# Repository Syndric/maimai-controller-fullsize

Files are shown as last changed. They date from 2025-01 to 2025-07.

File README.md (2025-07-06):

# Maimai Controller Fullsize

A fullsize homemade maimai machine.
Current guide can be found at [this google doc](https://docs.google.com/document/d/1rlUKWXb57IGA04_7nuOs167HQMNG2UHoSkpQwI1rv1U/edit?usp=sharing).
This guide is not finished yet, but most of the files you need to make the machine are here. READ CAREFULLY!
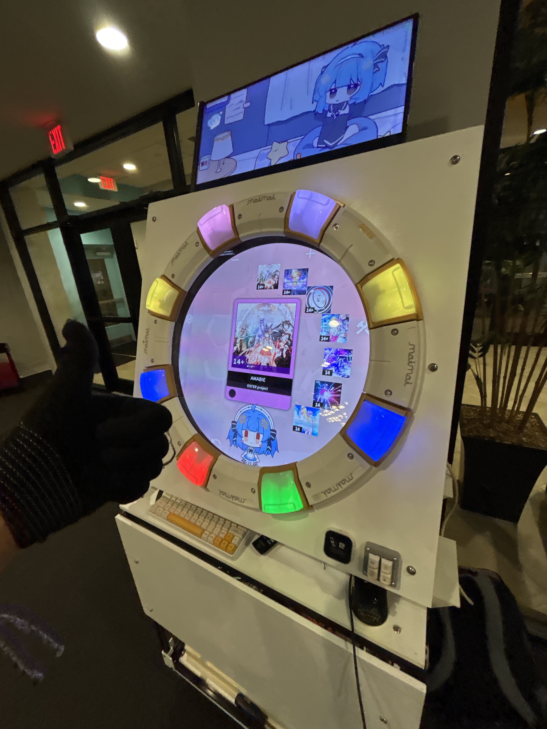
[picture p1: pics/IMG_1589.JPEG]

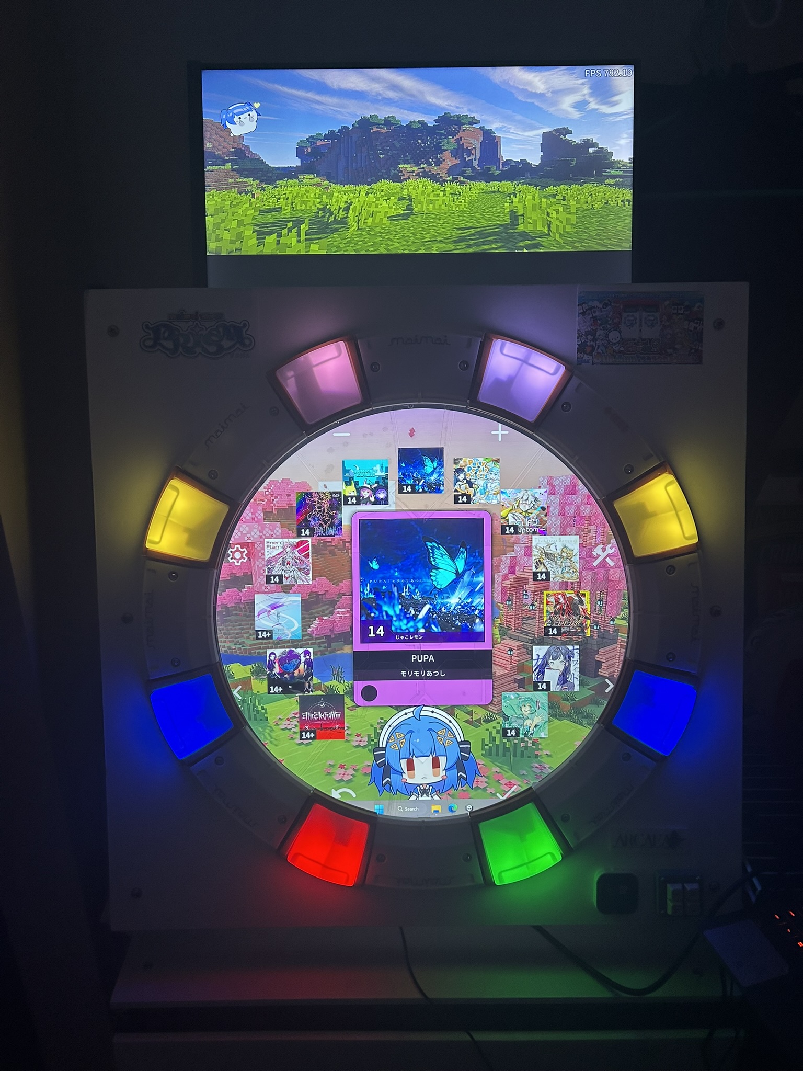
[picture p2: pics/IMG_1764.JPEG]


# Disclaimers

Read [Romper's fullsize guide](https://github.com/ir0nq/maimai-homemade-controller) before reading the instructions here.
DO NOT LASERCUT WITH THE ITO TEMPLATE AS IS. I'm not sure if the traces are wide enough. It's only good to be used for hand tracing/cut.
DO NOT MAKE THE CART IN MY DESIGN. It's not really stable.

I am NOT financially responsible for any mishaps you might have. This is only a guide. Double check all measurements.

# License

CC-NC, feel free to modify the project but don't make any money from this guide.

# Bill of Materials
Not complete

## PCB

- Raspberry Pi Nano
- USB C Connector
- 5.1k ohm resistor 0603
- 1uF capacitor 0603
- MPR121 Modules
- Dupont Pin headers
- JST XH 3 Pin connectors, headers
- 50m red wire
- 20m yellow wire
- 20m black wire
- SN74LV1T34DBVR Level shifter
- WS2812B RGB LED
- Mai pico IO PCB x1
- Syndric's RGB PCB x8

## Main Build

- Rabbit buttons
- ITO Film 40ohm 1m
- 43" TV
- 24" side-to-side Octagon glass
- Chair leg floor protectors
- 2020 48" Aluminum
- Small wood screws for buttons
- Wood screws for mai spacers
- Appropriate spacers

# Tools Needed

- Flathead screwdriver
- Philips screwdriver
- 3D printer
- Router
- Miter saw
- PPE

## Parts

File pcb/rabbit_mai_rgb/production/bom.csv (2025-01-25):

Designator | Footprint | Quantity | Value | LCSC Part #
C1, C2 | 0603 | 2 | C
D1, D2 | LED_WS2812B_PLCC4_5.0x5.0mm_P3.2mm | 2 | WS2812B
J1, J2 | JST_XH_S3B-XH-A_1x03_P2.50mm_Horizontal | 2 | Conn_01x03

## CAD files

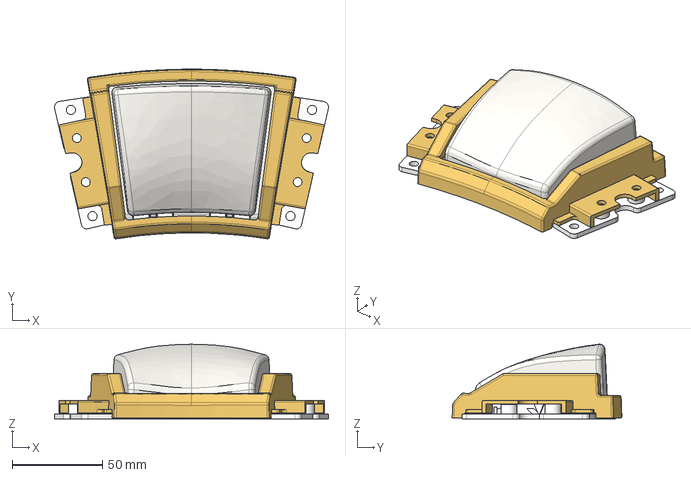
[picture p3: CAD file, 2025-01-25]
cad/Button/ButtonAssembly v7.iges
152.2 x 94.3 x 41.5 mm

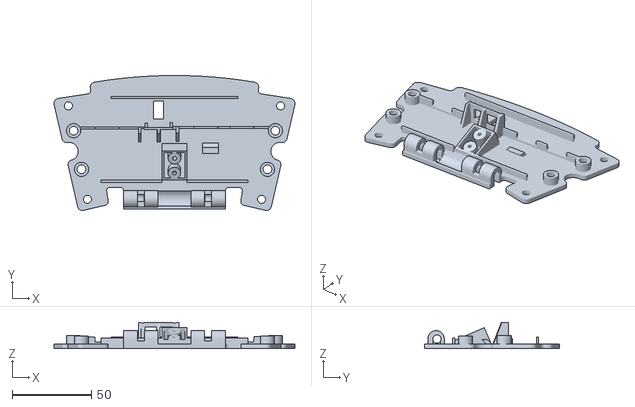
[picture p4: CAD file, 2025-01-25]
cad/Button/ButtonPlate v2.stl
152.2 x 85.3 x 16.4

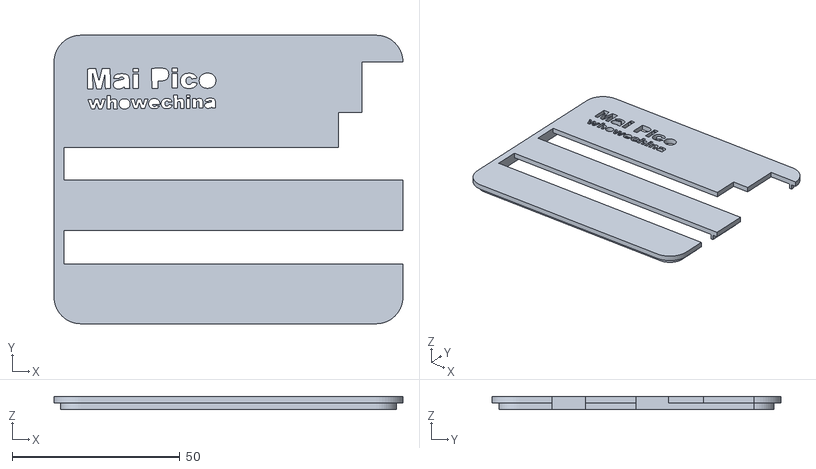
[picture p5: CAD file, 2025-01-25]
cad/IO Board/IOBoard v4_IOBoard v4_Cover_1_Body4.stl
104.0 x 86.0 x 4.00

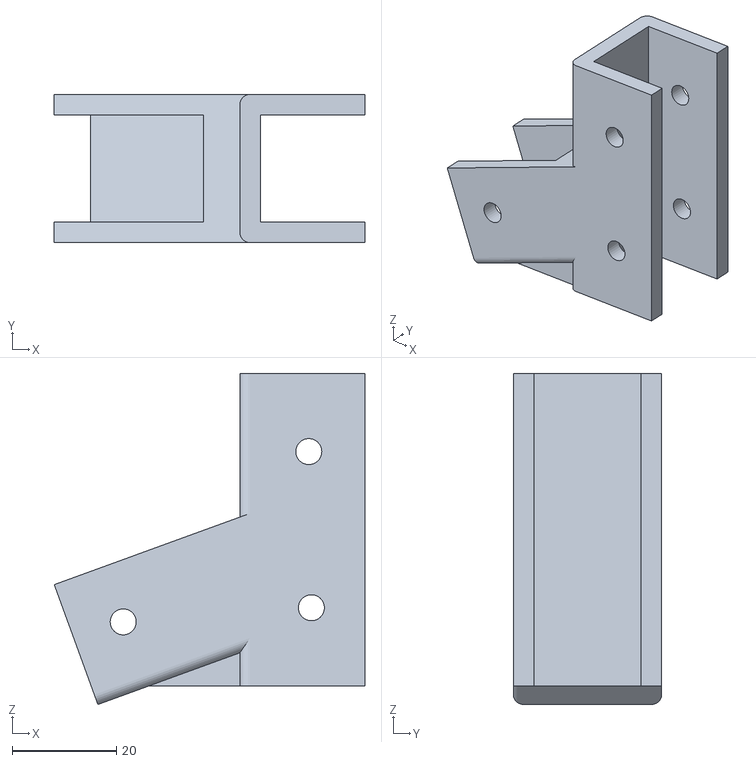
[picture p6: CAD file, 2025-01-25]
cad/Joints/StrongPlate2_70 v2.stl
59.6 x 28.5 x 63.6

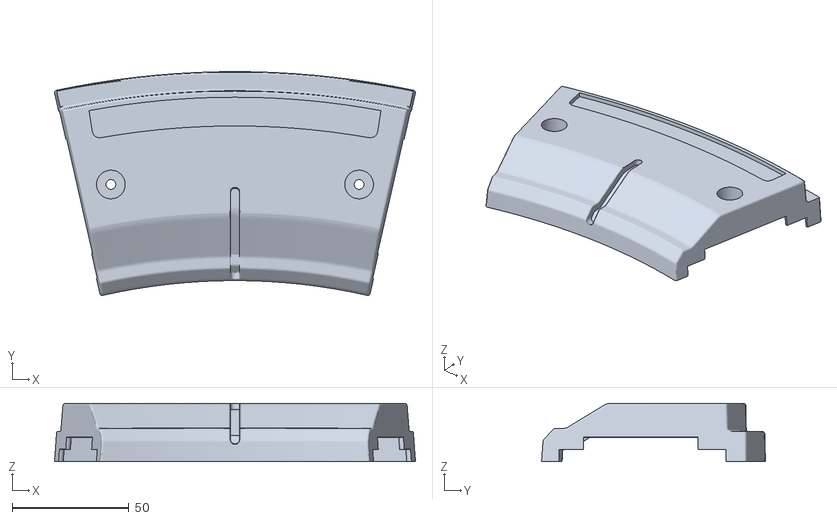
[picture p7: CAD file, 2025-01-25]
cad/Spacer/Maispacer_blank v12.stl
154.5 x 95.8 x 24.9

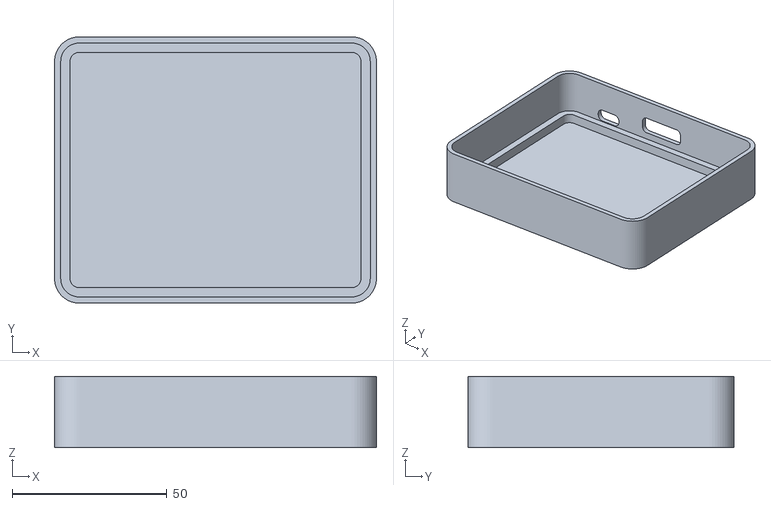
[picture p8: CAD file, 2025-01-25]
cad/IO Board/IOBoard v4_IOBoard v4_Box_1_Body1.stl
104.0 x 86.0 x 23.0

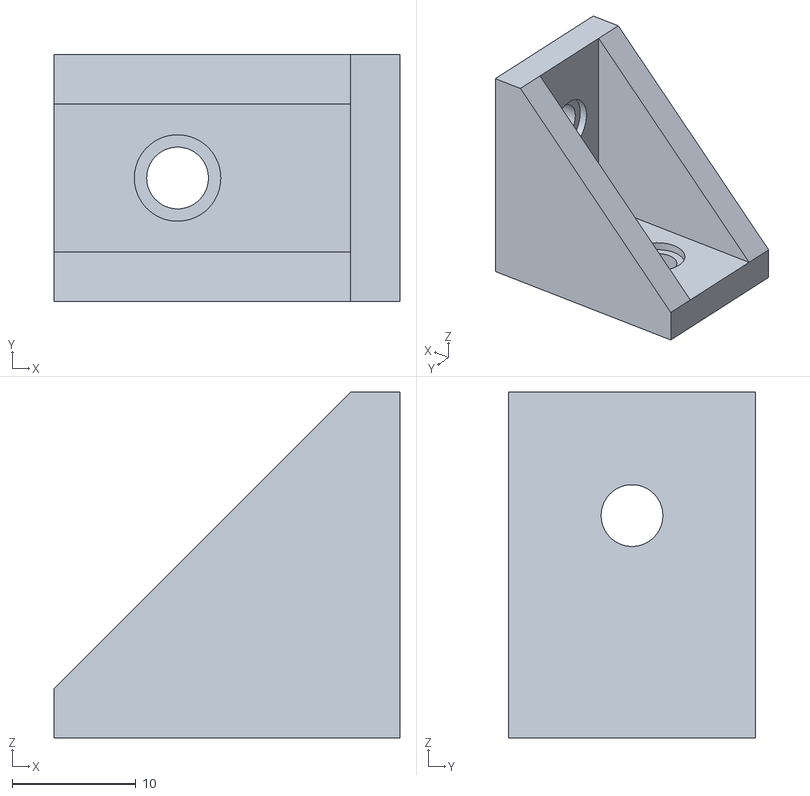
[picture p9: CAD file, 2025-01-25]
cad/Joints/angle bracket 90 v11 .stl
28.0 x 20.0 x 28.0

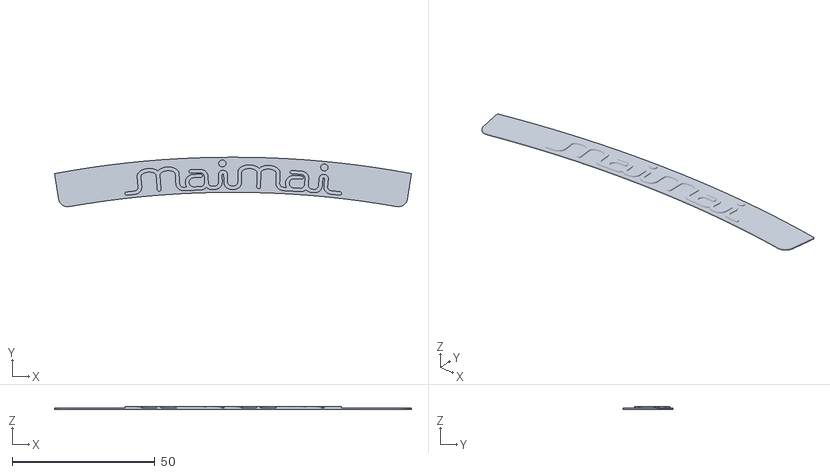
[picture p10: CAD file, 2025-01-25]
cad/Spacer/Maispacer_maidecal v6.stl
124.9 x 17.4 x 1.04

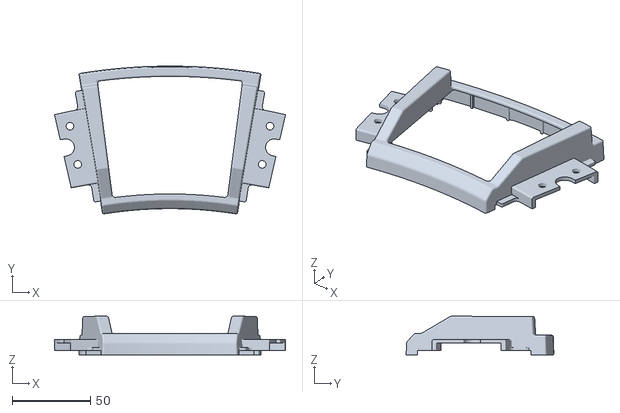
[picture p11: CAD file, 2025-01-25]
cad/Button/ButtonFrame v3.stl
147.4 x 94.3 x 24.6

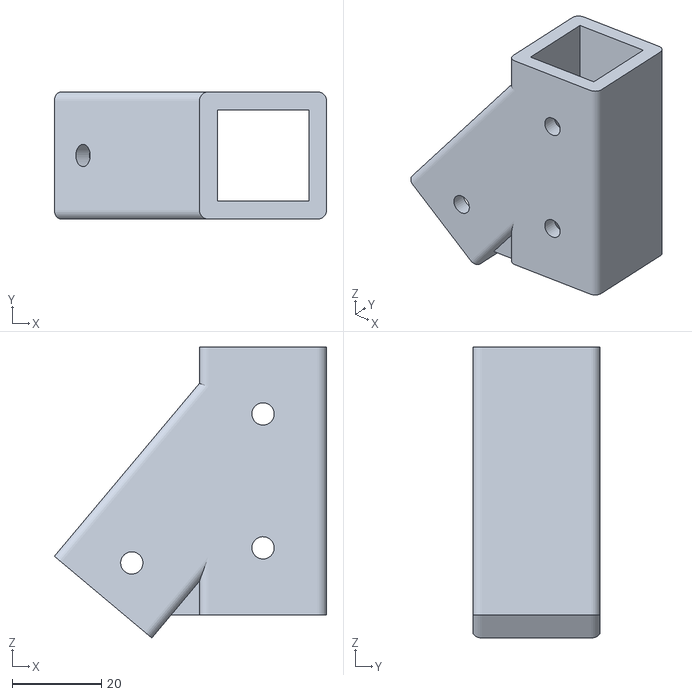
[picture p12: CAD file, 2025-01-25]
cad/Joints/StrongPlate40 v4.stl
61.0 x 28.5 x 65.2

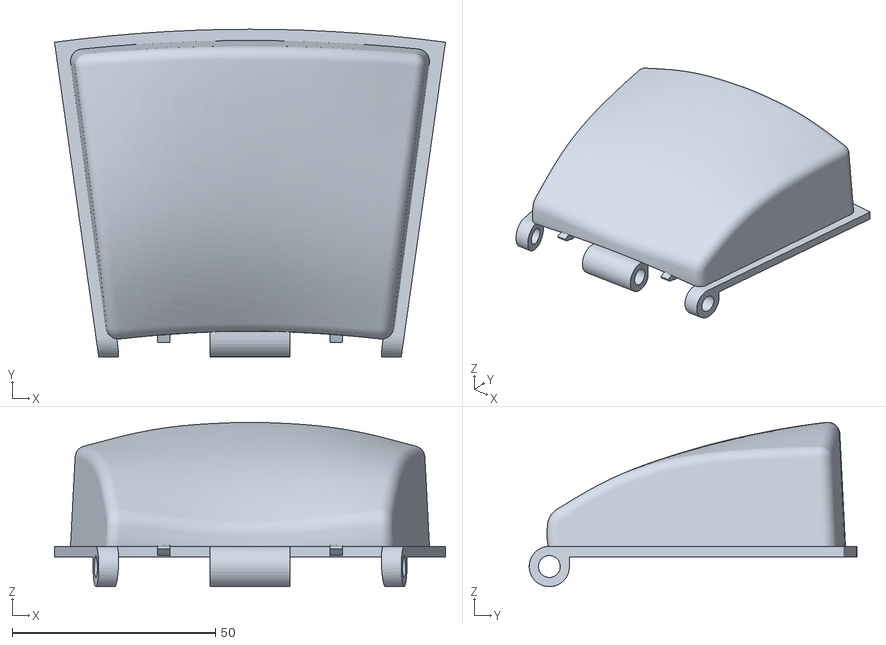
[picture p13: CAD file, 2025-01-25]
cad/Button/MaimaiButton v3.stl
96.3 x 80.6 x 40.5

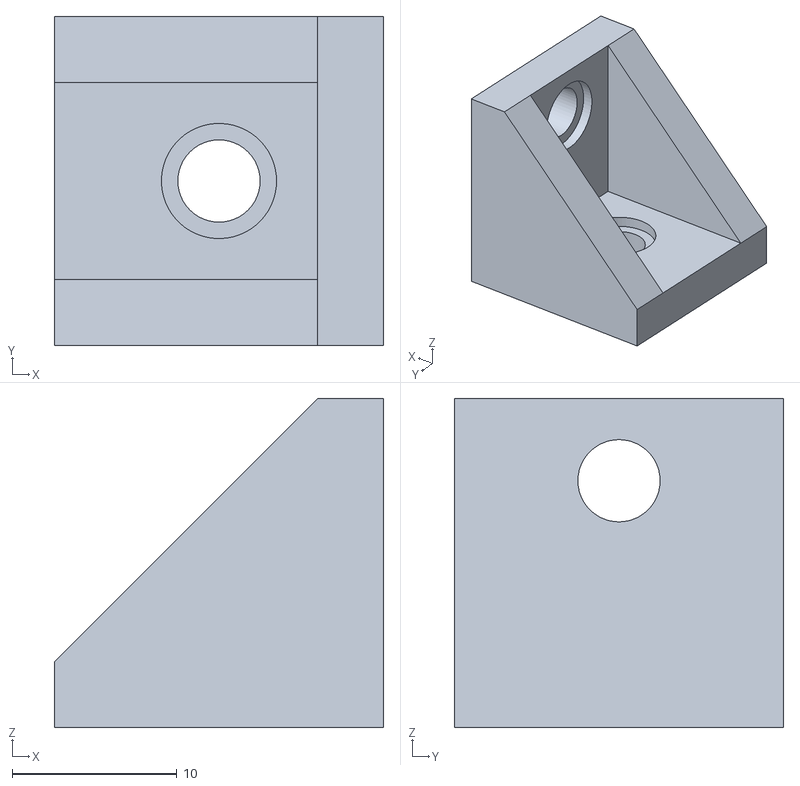
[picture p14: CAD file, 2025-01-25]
cad/Joints/angle bracket 90short v11.stl
20.0 x 20.0 x 20.0

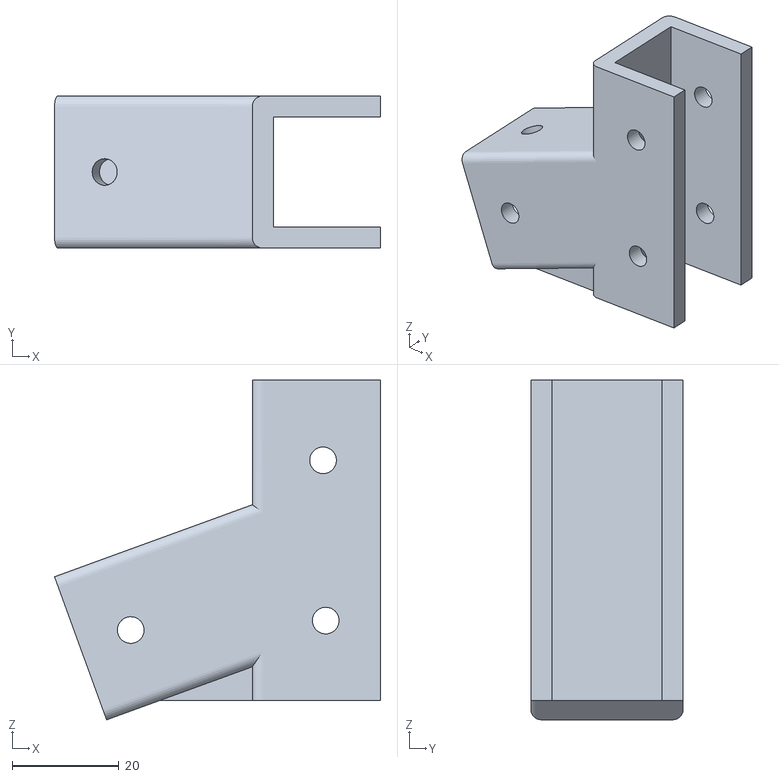
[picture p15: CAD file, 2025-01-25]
cad/Joints/StrongPlate70 v2.stl
61.0 x 28.5 x 63.6

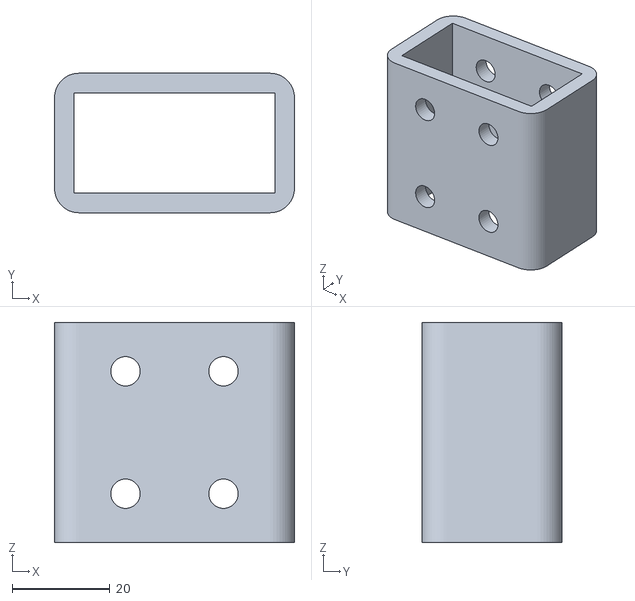
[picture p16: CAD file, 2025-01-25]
cad/Joints/JoiningPlate v6.stl
49.0 x 28.5 x 45.0

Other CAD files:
dxf/mai_pico_ito.dxf
dxf/mai_pico_ito_v1.dwg
dxf/mai_pico_ito_a4.dxf

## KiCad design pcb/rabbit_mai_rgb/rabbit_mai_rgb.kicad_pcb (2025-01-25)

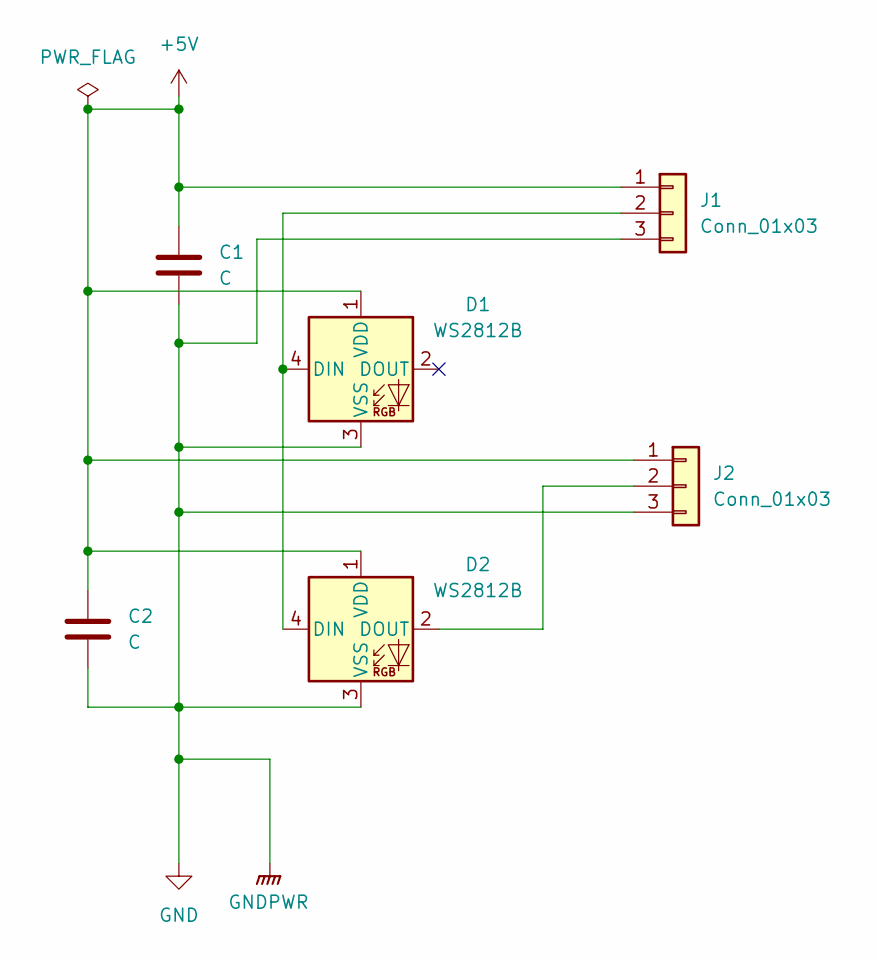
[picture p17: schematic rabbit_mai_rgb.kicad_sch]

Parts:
C1, C2: C; C_0603_1608Metric_Pad1.08x0.95mm_HandSolder
D1, D2: WS2812B; LED_WS2812B_PLCC4_5.0x5.0mm_P3.2mm
J1, J2: Conn_01x03; JST_XH_S3B-XH-A_1x03_P2.50mm_Horizontal

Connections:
+5V: C1.1, C2.1, D1.1 (VDD), D2.1 (VDD), J1.1, J2.1
GND: C1.2, C2.2, D1.3 (VSS), D2.3 (VSS), J1.3, J2.3
unnamed: D1.4 (DIN), D2.4 (DIN), J1.2
unnamed: D2.2 (DOUT), J2.2

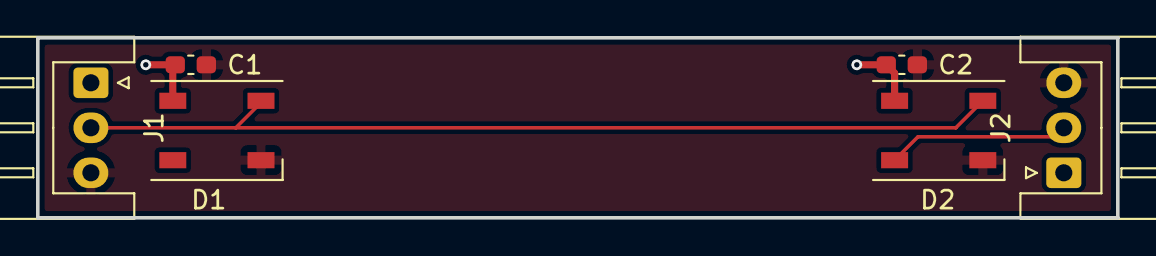
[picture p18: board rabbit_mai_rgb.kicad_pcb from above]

Board: 2 copper layers, 60.0 x 10.0 mm, 6 parts (0 on the bottom side), 4 nets.

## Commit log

2024-10-21 add button cad
    [ButtonFrame v3.step, ButtonPlate v2.step, MaimaiButton v3.step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]
2024-11-05 add maispacer
    [Maispacer_thick.3mf]
2025-01-25 add: basic files
    [ButtonAssembly v7.iges, ButtonFrame v3.step, ButtonFrame v3.stl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]
